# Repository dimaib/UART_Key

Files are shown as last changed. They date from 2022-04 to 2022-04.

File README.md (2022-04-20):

# Smart lock for city scooters
## Description
- This device allows you to block the scooter when charging, preventing premature removal from the rack
- The device also determines whether the scooter is rented or not, thereby blocking or giving it away
- Allows you to determine the speed of the scooter and dynamically change the color of the LED strip depending on the speed.
	>All data is intercepted from UART data line of the scooter.
## Tools and languages
- PCB and circuit diagram created by Altium Designer
- Firmware created in Keil uVision for ARM in C languages

## Main view PCB
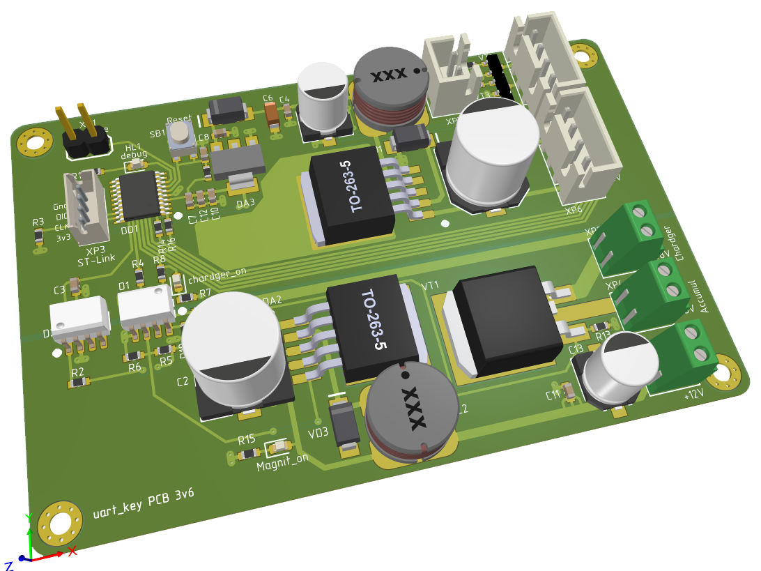
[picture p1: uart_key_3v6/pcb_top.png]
PCB top

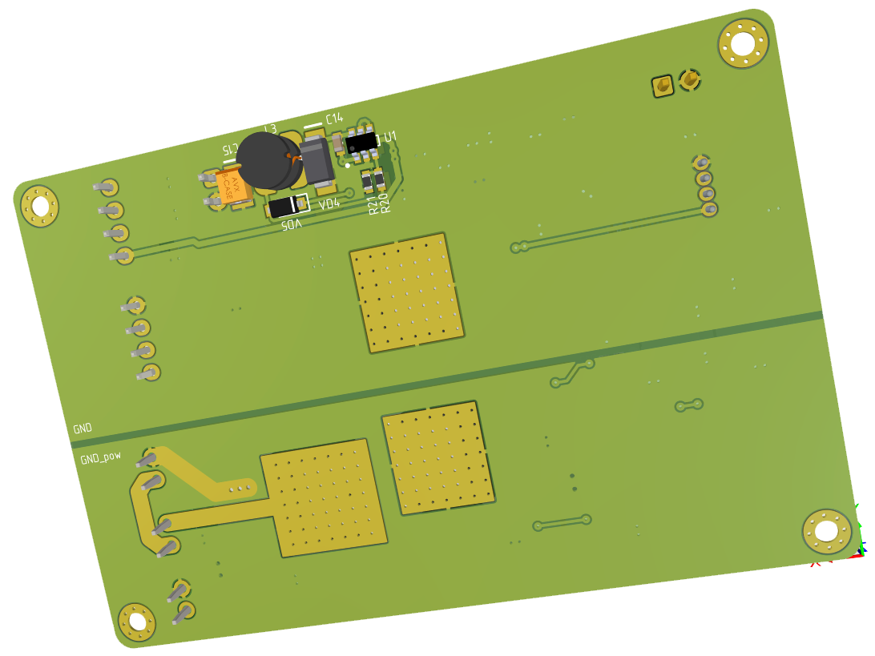
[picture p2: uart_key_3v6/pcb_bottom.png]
PCB bottom


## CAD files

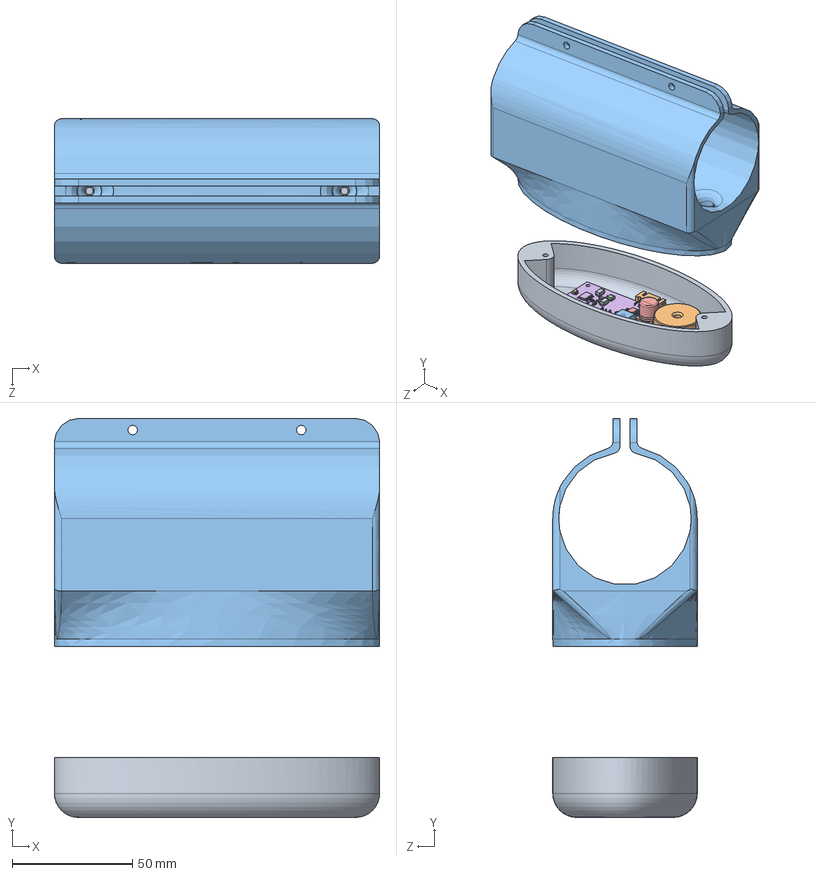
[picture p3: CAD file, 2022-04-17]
box_develop/box.SLDASM
135.0 x 165.6 x 60.0 mm
SOLID.step
SOLID-0.step
SOLID-1.step x 2
SOLID-2.step
SOLID-3.step
SOLID-4.step
SOLID-5.step x 12
SOLID-6.step x 3
SOLID-7.step x 3
SOLID-8.step x 4
SOLID-9.step
SOLID-10.step
COMPOUND.step
Magnet_conn
ZH_02x01_1.5mm
ZH_04x01_1.5mm
magnit
in_os

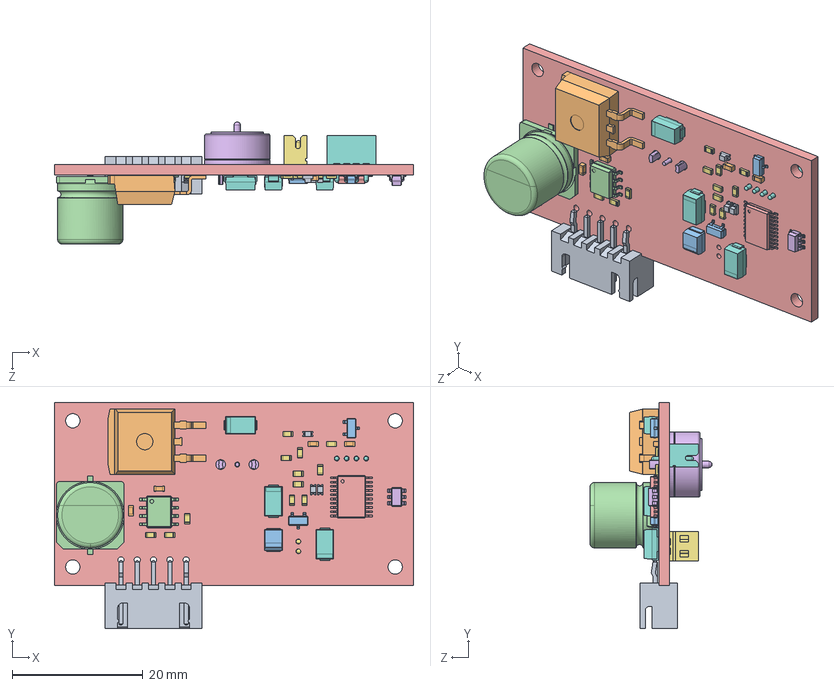
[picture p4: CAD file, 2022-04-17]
box_develop/pcb.SLDASM
55.0 x 34.6 x 18.7 mm
SOLID.step
SOLID-0.step
SOLID-1.step x 2
SOLID-2.step
SOLID-3.step
SOLID-4.step
SOLID-5.step x 12
SOLID-6.step x 3
SOLID-7.step x 3
SOLID-8.step x 4
SOLID-9.step
SOLID-10.step
COMPOUND.step
Magnet_conn
ZH_02x01_1.5mm
ZH_04x01_1.5mm

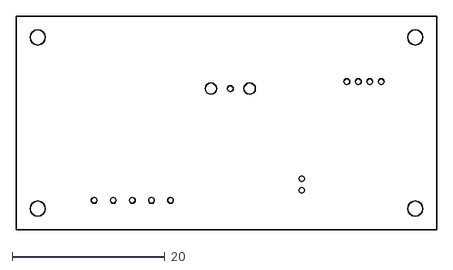
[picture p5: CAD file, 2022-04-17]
uart_key/123/uart_key-drl_map.dxf
55.0 x 28.0

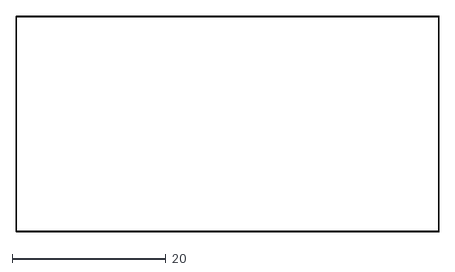
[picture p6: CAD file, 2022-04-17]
uart_key/uart_key-Edge_Cuts.dxf
55.1 x 28.1

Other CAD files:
box_develop/SOT-23.step.SLDASM
box_develop/SOT-23-6.step.SLDASM
box_develop/SOIC-8_3.9x4.9mm_P1.27mm.step.SLDASM
box_develop/TSSOP-20_4.4x6.5mm_P0.65mm.step.SLDASM
box_develop/CP_EIA-3528-21_Kemet-B.step.SLDASM
box_develop/D_SMA.step.SLDASM
box_develop/LED_0603_1608Metric_Castellated.step.SLDASM
box_develop/TO-263-2.step.SLDASM
box_develop/C_0603_1608Metric.step.SLDASM
box_develop/CP_Elec_10x10.5.step.SLDASM
box_develop/JST_XH_B5B-XH-A_1x05_P2.50mm_Vertical.step.SLDASM
box_develop/R_0603_1608Metric.step.SLDASM
box_develop/COMPOUND.step.SLDPRT
box_develop/Magnet_conn.SLDPRT
box_develop/SOLID-0.step.SLDPRT
box_develop/SOLID-1.step.SLDPRT
box_develop/SOLID-10.step.SLDPRT
box_develop/SOLID-2.step.SLDPRT
box_develop/SOLID-3.step.SLDPRT
box_develop/SOLID-4.step.SLDPRT
box_develop/SOLID-5.step.SLDPRT
box_develop/SOLID-6.step.SLDPRT
box_develop/SOLID-7.step.SLDPRT
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

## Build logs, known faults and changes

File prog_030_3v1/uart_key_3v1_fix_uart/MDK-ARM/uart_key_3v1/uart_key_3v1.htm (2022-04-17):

# Static Call Graph for image uart_key_3v1\uart_key_3v1.axf

#<CALLGRAPH># ARM Linker, 5060960: Last Updated: Sat May 29 01:21:32 2021

### Maximum Stack Usage = 216 bytes + Unknown(Cycles, Untraceable Function Pointers)

### Call chain for Maximum Stack Depth:

main ⇒ SystemClock_Config ⇒ HAL_RCC_ClockConfig ⇒ HAL_RCC_GetSysClockFreq ⇒ __aeabi_uldivmod ⇒ __aeabi_llsl

### Mutually Recursive functions

- ADC1_IRQHandler ⇒ ADC1_IRQHandler
- HardFault_Handler ⇒ HardFault_Handler
- NMI_Handler ⇒ NMI_Handler

### Function Pointers

- ADC1_IRQHandler from startup_stm32f030x6.o(.text) referenced from startup_stm32f030x6.o(RESET)
- DMA1_Channel1_IRQHandler from startup_stm32f030x6.o(.text) referenced from startup_stm32f030x6.o(RESET)
- DMA1_Channel2_3_IRQHandler from startup_stm32f030x6.o(.text) referenced from startup_stm32f030x6.o(RESET)
- DMA1_Channel4_5_IRQHandler from startup_stm32f030x6.o(.text) referenced from startup_stm32f030x6.o(RESET)
- EXTI0_1_IRQHandler from startup_stm32f030x6.o(.text) referenced from startup_stm32f030x6.o(RESET)
- EXTI2_3_IRQHandler from startup_stm32f030x6.o(.text) referenced from startup_stm32f030x6.o(RESET)
- EXTI4_15_IRQHandler from startup_stm32f030x6.o(.text) referenced from startup_stm32f030x6.o(RESET)
- FLASH_IRQHandler from startup_stm32f030x6.o(.text) referenced from startup_stm32f030x6.o(RESET)
- HardFault_Handler from stm32f0xx_it.o(i.HardFault_Handler) referenced from startup_stm32f030x6.o(RESET)
- I2C1_IRQHandler from startup_stm32f030x6.o(.text) referenced from startup_stm32f030x6.o(RESET)
- NMI_Handler from stm32f0xx_it.o(i.NMI_Handler) referenced from startup_stm32f030x6.o(RESET)
- PendSV_Handler from stm32f0xx_it.o(i.PendSV_Handler) referenced from startup_stm32f030x6.o(RESET)
- RCC_IRQHandler from startup_stm32f030x6.o(.text) referenced from startup_stm32f030x6.o(RESET)
- RTC_IRQHandler from startup_stm32f030x6.o(.text) referenced from startup_stm32f030x6.o(RESET)
- Reset_Handler from startup_stm32f030x6.o(.text) referenced from startup_stm32f030x6.o(RESET)
- SPI1_IRQHandler from startup_stm32f030x6.o(.text) referenced from startup_stm32f030x6.o(RESET)
- SVC_Handler from stm32f0xx_it.o(i.SVC_Handler) referenced from startup_stm32f030x6.o(RESET)
- SysTick_Handler from stm32f0xx_it.o(i.SysTick_Handler) referenced from startup_stm32f030x6.o(RESET)
- SystemInit from system_stm32f0xx.o(i.SystemInit) referenced from startup_stm32f030x6.o(.text)
- TIM14_IRQHandler from stm32f0xx_it.o(i.TIM14_IRQHandler) referenced from startup_stm32f030x6.o(RESET)
- TIM16_IRQHandler from startup_stm32f030x6.o(.text) referenced from startup_stm32f030x6.o(RESET)
- TIM17_IRQHandler from startup_stm32f030x6.o(.text) referenced from startup_stm32f030x6.o(RESET)
- TIM1_BRK_UP_TRG_COM_IRQHandler from startup_stm32f030x6.o(.text) referenced from startup_stm32f030x6.o(RESET)
- TIM1_CC_IRQHandler from startup_stm32f030x6.o(.text) referenced from startup_stm32f030x6.o(RESET)
- TIM3_IRQHandler from startup_stm32f030x6.o(.text) referenced from startup_stm32f030x6.o(RESET)
- UART_DMAAbortOnError from stm32f0xx_hal_uart.o(i.UART_DMAAbortOnError) referenced from stm32f0xx_hal_uart.o(i.HAL_UART_IRQHandler)
- USART1_IRQHandler from stm32f0xx_it.o(i.USART1_IRQHandler) referenced from startup_stm32f030x6.o(RESET)
- WWDG_IRQHandler from startup_stm32f030x6.o(.text) referenced from startup_stm32f030x6.o(RESET)
- __main from entry.o(.ARM.Collect$$$$00000000) referenced from startup_stm32f030x6.o(.text)
- main from main.o(i.main) referenced from entry9a.o(.ARM.Collect$$$$0000000B)

### Global Symbols

__main (Thumb, 0 bytes, Stack size unknown bytes, entry.o(.ARM.Collect$$$$00000000))
[Address Reference Count : 1]

- startup_stm32f030x6.o(.text)

_main_stk (Thumb, 0 bytes, Stack size unknown bytes, entry2.o(.ARM.Collect$$$$00000001))

_main_scatterload (Thumb, 0 bytes, Stack size unknown bytes, entry5.o(.ARM.Collect$$$$00000004))

[Calls]

- >> __scatterload

__main_after_scatterload (Thumb, 0 bytes, Stack size unknown bytes, entry5.o(.ARM.Collect$$$$00000004))

[Called By]

- >> __scatterload

_main_clock (Thumb, 0 bytes, Stack size unknown bytes, entry7b.o(.ARM.Collect$$$$00000008))

_main_cpp_init (Thumb, 0 bytes, Stack size unknown bytes, entry8b.o(.ARM.Collect$$$$0000000A))

_main_init (Thumb, 0 bytes, Stack size unknown bytes, entry9a.o(.ARM.Collect$$$$0000000B))

__rt_lib_shutdown_fini (Thumb, 0 bytes, Stack size unknown bytes, entry12b.o(.ARM.Collect$$$$0000000E))

[Calls]

- >> __arm_fini_ (Weak Reference)

__rt_final_cpp (Thumb, 0 bytes, Stack size unknown bytes, entry10a.o(.ARM.Collect$$$$0000000F))

__rt_final_exit (Thumb, 0 bytes, Stack size unknown bytes, entry11a.o(.ARM.Collect$$$$00000011))

Reset_Handler (Thumb, 8 bytes, Stack size 0 bytes, startup_stm32f030x6.o(.text))
[Address Reference Count : 1]

- startup_stm32f030x6.o(RESET)

ADC1_IRQHandler (Thumb, 0 bytes, Stack size 0 bytes, startup_stm32f030x6.o(.text))

[Calls]

- >> ADC1_IRQHandler

[Called By]

- >> ADC1_IRQHandler

[Address Reference Count : 1]

- startup_stm32f030x6.o(RESET)

DMA1_Channel1_IRQHandler (Thumb, 0 bytes, Stack size 0 bytes, startup_stm32f030x6.o(.text))
[Address Reference Count : 1]

- startup_stm32f030x6.o(RESET)

DMA1_Channel2_3_IRQHandler (Thumb, 0 bytes, Stack size 0 bytes, startup_stm32f030x6.o(.text))
[Address Reference Count : 1]

- startup_stm32f030x6.o(RESET)

DMA1_Channel4_5_IRQHandler (Thumb, 0 bytes, Stack size 0 bytes, startup_stm32f030x6.o(.text))
[Address Reference Count : 1]

- startup_stm32f030x6.o(RESET)

EXTI0_1_IRQHandler (Thumb, 0 bytes, Stack size 0 bytes, startup_stm32f030x6.o(.text))
[Address Reference Count : 1]

- startup_stm32f030x6.o(RESET)

EXTI2_3_IRQHandler (Thumb, 0 bytes, Stack size 0 bytes, startup_stm32f030x6.o(.text))
[Address Reference Count : 1]

- startup_stm32f030x6.o(RESET)

EXTI4_15_IRQHandler (Thumb, 0 bytes, Stack size 0 bytes, startup_stm32f030x6.o(.text))
[Address Reference Count : 1]

- startup_stm32f030x6.o(RESET)

FLASH_IRQHandler (Thumb, 0 bytes, Stack size 0 bytes, startup_stm32f030x6.o(.text))
[Address Reference Count : 1]

- startup_stm32f030x6.o(RESET)

I2C1_IRQHandler (Thumb, 0 bytes, Stack size 0 bytes, startup_stm32f030x6.o(.text))
[Address Reference Count : 1]

- startup_stm32f030x6.o(RESET)

RCC_IRQHandler (Thumb, 0 bytes, Stack size 0 bytes, startup_stm32f030x6.o(.text))
[Address Reference Count : 1]

- startup_stm32f030x6.o(RESET)

RTC_IRQHandler (Thumb, 0 bytes, Stack size 0 bytes, startup_stm32f030x6.o(.text))
[Address Reference Count : 1]

- startup_stm32f030x6.o(RESET)

SPI1_IRQHandler (Thumb, 0 bytes, Stack size 0 bytes, startup_stm32f030x6.o(.text))
[Address Reference Count : 1]

- startup_stm32f030x6.o(RESET)

TIM16_IRQHandler (Thumb, 0 bytes, Stack size 0 bytes, startup_stm32f030x6.o(.text))
[Address Reference Count : 1]

- startup_stm32f030x6.o(RESET)

TIM17_IRQHandler (Thumb, 0 bytes, Stack size 0 bytes, startup_stm32f030x6.o(.text))
[Address Reference Count : 1]

- startup_stm32f030x6.o(RESET)

TIM1_BRK_UP_TRG_COM_IRQHandler (Thumb, 0 bytes, Stack size 0 bytes, startup_stm32f030x6.o(.text))
[Address Reference Count : 1]

- startup_stm32f030x6.o(RESET)

TIM1_CC_IRQHandler (Thumb, 0 bytes, Stack size 0 bytes, startup_stm32f030x6.o(.text))
[Address Reference Count : 1]

- startup_stm32f030x6.o(RESET)

TIM3_IRQHandler (Thumb, 0 bytes, Stack size 0 bytes, startup_stm32f030x6.o(.text))
[Address Reference Count : 1]

- startup_stm32f030x6.o(RESET)

WWDG_IRQHandler (Thumb, 0 bytes, Stack size 0 bytes, startup_stm32f030x6.o(.text))
[Address Reference Count : 1]

- startup_stm32f030x6.o(RESET)

__aeabi_uidiv (Thumb, 0 bytes, Stack size 12 bytes, uidiv.o(.text), UNUSED)

__aeabi_uidivmod (Thumb, 44 bytes, Stack size 12 bytes, uidiv.o(.text))

[Stack]

- Max Depth = 12
- Call Chain = __aeabi_uidivmod

[Called By]

- >> HAL_InitTick
- >> UART_SetConfig

__aeabi_uldivmod (Thumb, 96 bytes, Stack size 48 bytes, uldiv.o(.text))

[Stack]

- Max Depth = 56
- Call Chain = __aeabi_uldivmod ⇒ __aeabi_llsl

[Calls]

- >> __aeabi_llsl
- >> __aeabi_llsr

[Called By]

- >> HAL_RCC_GetSysClockFreq

__aeabi_llsr (Thumb, 34 bytes, Stack size 8 bytes, llushr.o(.text))

[Stack]

- Max Depth = 8
- Call Chain = __aeabi_llsr

[Called By]

- >> __aeabi_uldivmod

_ll_ushift_r (Thumb, 0 bytes, Stack size 8 bytes, llushr.o(.text), UNUSED)

__aeabi_memset (Thumb, 14 bytes, Stack size 0 bytes, memseta.o(.text), UNUSED)

[Called By]

- >> _memset$wrapper
- >> __aeabi_memclr

__aeabi_memset4 (Thumb, 0 bytes, Stack size 0 bytes, memseta.o(.text), UNUSED)

__aeabi_memset8 (Thumb, 0 bytes, Stack size 0 bytes, memseta.o(.text), UNUSED)

__aeabi_memclr (Thumb, 4 bytes, Stack size 0 bytes, memseta.o(.text), UNUSED)

[Calls]

- >> __aeabi_memset

__aeabi_memclr4 (Thumb, 0 bytes, Stack size 0 bytes, memseta.o(.text))

[Called By]

- >> HAL_UART_MspInit
- >> MX_GPIO_Init
- >> SystemClock_Config

__aeabi_memclr8 (Thumb, 0 bytes, Stack size 0 bytes, memseta.o(.text), UNUSED)

_memset$wrapper (Thumb, 18 bytes, Stack size 8 bytes, memseta.o(.text), UNUSED)

[Calls]

- >> __aeabi_memset

__aeabi_llsl (Thumb, 32 bytes, Stack size 8 bytes, llshl.o(.text))

[Stack]

- Max Depth = 8
- Call Chain = __aeabi_llsl

[Called By]

- >> __aeabi_uldivmod

_ll_shift_l (Thumb, 0 bytes, Stack size 8 bytes, llshl.o(.text), UNUSED)

__scatterload (Thumb, 28 bytes, Stack size 0 bytes, init.o(.text))

[Calls]

- >> __main_after_scatterload

[Called By]

- >> _main_scatterload

__scatterload_rt2 (Thumb, 0 bytes, Stack size 0 bytes, init.o(.text), UNUSED)

Error_Handler (Thumb, 4 bytes, Stack size 0 bytes, main.o(i.Error_Handler))

[Called By]

- >> MX_USART1_UART_Init
- >> MX_TIM14_Init
- >> MX_IWDG_Init

HAL_DMA_Abort_IT (Thumb, 72 bytes, Stack size 16 bytes, stm32f0xx_hal_dma.o(i.HAL_DMA_Abort_IT))

[Stack]

- Max Depth = 16
- Call Chain = HAL_DMA_Abort_IT

[Called By]

- >> HAL_UART_IRQHandler

HAL_Delay (Thumb, 32 bytes, Stack size 16 bytes, stm32f0xx_hal.o(i.HAL_Delay))

[Stack]

- Max Depth = 16
- Call Chain = HAL_Delay

[Calls]

- >> HAL_GetTick

[Called By]

- >> main
- >> command_shell

HAL_GPIO_Init (Thumb, 344 bytes, Stack size 28 bytes, stm32f0xx_hal_gpio.o(i.HAL_GPIO_Init))

[Stack]

- Max Depth = 28
- Call Chain = HAL_GPIO_Init

[Called By]

- >> HAL_UART_MspInit
- >> MX_GPIO_Init

HAL_GPIO_WritePin (Thumb, 12 bytes, Stack size 0 bytes, stm32f0xx_hal_gpio.o(i.HAL_GPIO_WritePin))

[Called By]

- >> MX_GPIO_Init

HAL_GetTick (Thumb, 6 bytes, Stack size 0 bytes, stm32f0xx_hal.o(i.HAL_GetTick))

[Called By]

- >> HAL_IWDG_Init
- >> HAL_RCC_OscConfig
- >> HAL_RCC_ClockConfig
- >> HAL_RCCEx_PeriphCLKConfig
- >> HAL_Delay
- >> UART_WaitOnFlagUntilTimeout
- >> UART_CheckIdleState

HAL_IWDG_Init (Thumb, 86 bytes, Stack size 16 bytes, stm32f0xx_hal_iwdg.o(i.HAL_IWDG_Init))

[Stack]

- Max Depth = 16
- Call Chain = HAL_IWDG_Init

[Calls]

- >> HAL_GetTick

[Called By]

- >> MX_IWDG_Init

HAL_IncTick (Thumb, 12 bytes, Stack size 0 bytes, stm32f0xx_hal.o(i.HAL_IncTick))

[Called By]

- >> SysTick_Handler

HAL_Init (Thumb, 26 bytes, Stack size 8 bytes, stm32f0xx_hal.o(i.HAL_Init))

[Stack]

- Max Depth = 36
- Call Chain = HAL_Init ⇒ HAL_InitTick ⇒ __aeabi_uidivmod

[Calls]

- >> HAL_InitTick
- >> HAL_MspInit

[Called By]

- >> main

HAL_InitTick (Thumb, 58 bytes, Stack size 16 bytes, stm32f0xx_hal.o(i.HAL_InitTick))

[Stack]

- Max Depth = 28
- Call Chain = HAL_InitTick ⇒ __aeabi_uidivmod

[Calls]

- >> HAL_SYSTICK_Config
- >> HAL_NVIC_SetPriority
- >> __aeabi_uidivmod

[Called By]

- >> HAL_RCC_ClockConfig
- >> HAL_Init

HAL_MspInit (Thumb, 34 bytes, Stack size 8 bytes, stm32f0xx_hal_msp.o(i.HAL_MspInit))

[Stack]

- Max Depth = 8
- Call Chain = HAL_MspInit

[Called By]

- >> HAL_Init

HAL_NVIC_EnableIRQ (Thumb, 18 bytes, Stack size 0 bytes, stm32f0xx_hal_cortex.o(i.HAL_NVIC_EnableIRQ))

[Called By]

- >> HAL_UART_MspInit
- >> HAL_TIM_Base_MspInit

HAL_NVIC_SetPriority (Thumb, 8 bytes, Stack size 8 bytes, stm32f0xx_hal_cortex.o(i.HAL_NVIC_SetPriority))

[Stack]

- Max Depth = 8
- Call Chain = HAL_NVIC_SetPriority

[Calls]

- >> __NVIC_SetPriority

[Called By]

- >> HAL_InitTick
- >> HAL_UART_MspInit
- >> HAL_TIM_Base_MspInit

HAL_RCCEx_PeriphCLKConfig (Thumb, 218 bytes, Stack size 24 bytes, stm32f0xx_hal_rcc_ex.o(i.HAL_RCCEx_PeriphCLKConfig))

[Stack]

- Max Depth = 24
- Call Chain = HAL_RCCEx_PeriphCLKConfig

[Calls]

- >> HAL_GetTick

[Called By]

- >> SystemClock_Config

HAL_RCC_ClockConfig (Thumb, 242 bytes, Stack size 24 bytes, stm32f0xx_hal_rcc.o(i.HAL_RCC_ClockConfig))

[Stack]

- Max Depth = 120
- Call Chain = HAL_RCC_ClockConfig ⇒ HAL_RCC_GetSysClockFreq ⇒ __aeabi_uldivmod ⇒ __aeabi_llsl

[Calls]

- >> HAL_InitTick
- >> HAL_RCC_GetSysClockFreq
- >> HAL_GetTick

[Called By]

- >> SystemClock_Config

HAL_RCC_GetPCLK1Freq (Thumb, 20 bytes, Stack size 0 bytes, stm32f0xx_hal_rcc.o(i.HAL_RCC_GetPCLK1Freq))

[Called By]

- >> UART_SetConfig

HAL_RCC_GetSysClockFreq (Thumb, 84 bytes, Stack size 40 bytes, stm32f0xx_hal_rcc.o(i.HAL_RCC_GetSysClockFreq))

[Stack]

- Max Depth = 96
- Call Chain = HAL_RCC_GetSysClockFreq ⇒ __aeabi_uldivmod ⇒ __aeabi_llsl

[Calls]

- >> __ARM_common_ll_muluu
- >> __aeabi_uldivmod

[Called By]

- >> HAL_RCC_ClockConfig
- >> UART_SetConfig

HAL_RCC_OscConfig (Thumb, 890 bytes, Stack size 32 bytes, stm32f0xx_hal_rcc.o(i.HAL_RCC_OscConfig))

[Stack]

- Max Depth = 32
- Call Chain = HAL_RCC_OscConfig

[Calls]

- >> HAL_GetTick

[Called By]

- >> SystemClock_Config

HAL_SYSTICK_Config (Thumb, 38 bytes, Stack size 8 bytes, stm32f0xx_hal_cortex.o(i.HAL_SYSTICK_Config))

[Stack]

- Max Depth = 8
- Call Chain = HAL_SYSTICK_Config

[Calls]

- >> __NVIC_SetPriority

[Called By]

- >> HAL_InitTick

HAL_TIMEx_BreakCallback (Thumb, 2 bytes, Stack size 0 bytes, stm32f0xx_hal_tim_ex.o(i.HAL_TIMEx_BreakCallback))

[Called By]

- >> HAL_TIM_IRQHandler

HAL_TIMEx_CommutCallback (Thumb, 2 bytes, Stack size 0 bytes, stm32f0xx_hal_tim_ex.o(i.HAL_TIMEx_CommutCallback))

[Called By]

- >> HAL_TIM_IRQHandler

HAL_TIM_Base_Init (Thumb, 52 bytes, Stack size 16 bytes, stm32f0xx_hal_tim.o(i.HAL_TIM_Base_Init))

[Stack]

- Max Depth = 32
- Call Chain = HAL_TIM_Base_Init ⇒ HAL_TIM_Base_MspInit ⇒ HAL_NVIC_SetPriority

[Calls]

- >> HAL_TIM_Base_MspInit
- >> TIM_Base_SetConfig

[Called By]

- >> MX_TIM14_Init

HAL_TIM_Base_MspInit (Thumb, 44 bytes, Stack size 8 bytes, tim.o(i.HAL_TIM_Base_MspInit))

[Stack]

- Max Depth = 16
- Call Chain = HAL_TIM_Base_MspInit ⇒ HAL_NVIC_SetPriority

[Calls]

- >> HAL_NVIC_SetPriority
- >> HAL_NVIC_EnableIRQ

[Called By]

- >> HAL_TIM_Base_Init

HAL_TIM_Base_Start_IT (Thumb, 32 bytes, Stack size 0 bytes, stm32f0xx_hal_tim.o(i.HAL_TIM_Base_Start_IT))

[Called By]

- >> main

HAL_TIM_IC_CaptureCallback (Thumb, 2 bytes, Stack size 0 bytes, stm32f0xx_hal_tim.o(i.HAL_TIM_IC_CaptureCallback))

[Called By]

- >> HAL_TIM_IRQHandler

HAL_TIM_IRQHandler (Thumb, 354 bytes, Stack size 16 bytes, stm32f0xx_hal_tim.o(i.HAL_TIM_IRQHandler))

[Stack]

- Max Depth = 16
- Call Chain = HAL_TIM_IRQHandler

[Calls]

- >> HAL_TIM_TriggerCallback
- >> HAL_TIM_PeriodElapsedCallback
- >> HAL_TIM_PWM_PulseFinishedCallback
- >> HAL_TIM_OC_DelayElapsedCallback
- >> HAL_TIM_IC_CaptureCallback
- >> HAL_TIMEx_CommutCallback
- >> HAL_TIMEx_BreakCallback

[Called By]

- >> TIM14_IRQHandler

HAL_TIM_OC_DelayElapsedCallback (Thumb, 2 bytes, Stack size 0 bytes, stm32f0xx_hal_tim.o(i.HAL_TIM_OC_DelayElapsedCallback))

[Called By]

- >> HAL_TIM_IRQHandler

HAL_TIM_PWM_PulseFinishedCallback (Thumb, 2 bytes, Stack size 0 bytes, stm32f0xx_hal_tim.o(i.HAL_TIM_PWM_PulseFinishedCallback))

[Called By]

- >> HAL_TIM_IRQHandler

HAL_TIM_PeriodElapsedCallback (Thumb, 2 bytes, Stack size 0 bytes, stm32f0xx_hal_tim.o(i.HAL_TIM_PeriodElapsedCallback))

[Called By]

- >> HAL_TIM_IRQHandler

HAL_TIM_TriggerCallback (Thumb, 2 bytes, Stack size 0 bytes, stm32f0xx_hal_tim.o(i.HAL_TIM_TriggerCallback))

[Called By]

- >> HAL_TIM_IRQHandler

HAL_UART_ErrorCallback (Thumb, 2 bytes, Stack size 0 bytes, stm32f0xx_hal_uart.o(i.HAL_UART_ErrorCallback))

[Called By]

- >> HAL_UART_IRQHandler
- >> UART_DMAAbortOnError

HAL_UART_IRQHandler (Thumb, 320 bytes, Stack size 24 bytes, stm32f0xx_hal_uart.o(i.HAL_UART_IRQHandler))

[Stack]

- Max Depth = 40
- Call Chain = HAL_UART_IRQHandler ⇒ HAL_DMA_Abort_IT

[Calls]

- >> HAL_DMA_Abort_IT
- >> HAL_UART_TxCpltCallback
- >> HAL_UART_ErrorCallback
- >> UART_EndRxTransfer

[Called By]

- >> USART1_IRQHandler

HAL_UART_Init (Thumb, 106 bytes, Stack size 8 bytes, stm32f0xx_hal_uart.o(i.HAL_UART_Init))

[Stack]

- Max Depth = 120
- Call Chain = HAL_UART_Init ⇒ UART_SetConfig ⇒ HAL_RCC_GetSysClockFreq ⇒ __aeabi_uldivmod ⇒ __aeabi_llsl

[Calls]

- >> HAL_UART_MspInit
- >> UART_SetConfig
- >> UART_CheckIdleState
- >> UART_AdvFeatureConfig

[Called By]

- >> MX_USART1_UART_Init

HAL_UART_MspInit (Thumb, 106 bytes, Stack size 32 bytes, usart.o(i.HAL_UART_MspInit))

[Stack]

- Max Depth = 60
- Call Chain = HAL_UART_MspInit ⇒ HAL_GPIO_Init

[Calls]

- >> HAL_NVIC_SetPriority
- >> HAL_NVIC_EnableIRQ
- >> HAL_GPIO_Init
- >> __aeabi_memclr4

[Called By]

- >> HAL_UART_Init

HAL_UART_TxCpltCallback (Thumb, 2 bytes, Stack size 0 bytes, stm32f0xx_hal_uart.o(i.HAL_UART_TxCpltCallback))

[Called By]

- >> HAL_UART_IRQHandler

HardFault_Handler (Thumb, 2 bytes, Stack size 0 bytes, stm32f0xx_it.o(i.HardFault_Handler))

[Calls]

- >> HardFault_Handler

[Called By]

- >> HardFault_Handler

[Address Reference Count : 1]

- startup_stm32f030x6.o(RESET)

MX_GPIO_Init (Thumb, 156 bytes, Stack size 48 bytes, gpio.o(i.MX_GPIO_Init))

[Stack]

- Max Depth = 76
- Call Chain = MX_GPIO_Init ⇒ HAL_GPIO_Init

[Calls]

- >> HAL_GPIO_WritePin
- >> HAL_GPIO_Init
- >> __aeabi_memclr4

[Called By]

- >> main

MX_IWDG_Init (Thumb, 34 bytes, Stack size 8 bytes, iwdg.o(i.MX_IWDG_Init))

[Stack]

- Max Depth = 24
- Call Chain = MX_IWDG_Init ⇒ HAL_IWDG_Init

[Calls]

- >> HAL_IWDG_Init
- >> Error_Handler

[Called By]

- >> main

MX_TIM14_Init (Thumb, 38 bytes, Stack size 8 bytes, tim.o(i.MX_TIM14_Init))

[Stack]

- Max Depth = 40
- Call Chain = MX_TIM14_Init ⇒ HAL_TIM_Base_Init ⇒ HAL_TIM_Base_MspInit ⇒ HAL_NVIC_SetPriority

[Calls]

- >> HAL_TIM_Base_Init
- >> Error_Handler

[Called By]

- >> main

MX_USART1_UART_Init (Thumb, 48 bytes, Stack size 8 bytes, usart.o(i.MX_USART1_UART_Init))

[Stack]

- Max Depth = 128
- Call Chain = MX_USART1_UART_Init ⇒ HAL_UART_Init ⇒ UART_SetConfig ⇒ HAL_RCC_GetSysClockFreq ⇒ __aeabi_uldivmod ⇒ __aeabi_llsl

[Calls]

- >> HAL_UART_Init
- >> Error_Handler

[Called By]

- >> main

NMI_Handler (Thumb, 2 bytes, Stack size 0 bytes, stm32f0xx_it.o(i.NMI_Handler))

[Calls]

- >> NMI_Handler

[Called By]

- >> NMI_Handler

[Address Reference Count : 1]

- startup_stm32f030x6.o(RESET)

PendSV_Handler (Thumb, 2 bytes, Stack size 0 bytes, stm32f0xx_it.o(i.PendSV_Handler))
[Address Reference Count : 1]

- startup_stm32f030x6.o(RESET)

SVC_Handler (Thumb, 2 bytes, Stack size 0 bytes, stm32f0xx_it.o(i.SVC_Handler))
[Address Reference Count : 1]

- startup_stm32f030x6.o(RESET)

SysTick_Handler (Thumb, 8 bytes, Stack size 8 bytes, stm32f0xx_it.o(i.SysTick_Handler))

[Stack]

- Max Depth = 8
- Call Chain = SysTick_Handler

[Calls]

- >> HAL_IncTick

[Address Reference Count : 1]

- startup_stm32f030x6.o(RESET)

SystemClock_Config (Thumb, 120 bytes, Stack size 96 bytes, main.o(i.SystemClock_Config))

[Stack]

- Max Depth = 216
- Call Chain = SystemClock_Config ⇒ HAL_RCC_ClockConfig ⇒ HAL_RCC_GetSysClockFreq ⇒ __aeabi_uldivmod ⇒ __aeabi_llsl

[Calls]

- >> HAL_RCC_OscConfig
- >> HAL_RCC_ClockConfig
- >> HAL_RCCEx_PeriphCLKConfig
- >> __aeabi_memclr4

[Called By]

- >> main

SystemInit (Thumb, 2 bytes, Stack size 0 bytes, system_stm32f0xx.o(i.SystemInit))
[Address Reference Count : 1]

- startup_stm32f030x6.o(.text)

TIM14_IRQHandler (Thumb, 86 bytes, Stack size 8 bytes, stm32f0xx_it.o(i.TIM14_IRQHandler))

[Stack]

- Max Depth = 24
- Call Chain = TIM14_IRQHandler ⇒ HAL_TIM_IRQHandler

[Calls]

- >> HAL_TIM_IRQHandler

[Address Reference Count : 1]

- startup_stm32f030x6.o(RESET)

TIM_Base_SetConfig (Thumb, 100 bytes, Stack size 16 bytes, stm32f0xx_hal_tim.o(i.TIM_Base_SetConfig))

[Stack]

- Max Depth = 16
- Call Chain = TIM_Base_SetConfig

[Called By]

- >> HAL_TIM_Base_Init

UART_AdvFeatureConfig (Thumb, 202 bytes, Stack size 8 bytes, stm32f0xx_hal_uart.o(i.UART_AdvFeatureConfig))

[Stack]

- Max Depth = 8
- Call Chain = UART_AdvFeatureConfig

[Called By]

- >> HAL_UART_Init

UART_CheckIdleState (Thumb, 90 bytes, Stack size 24 bytes, stm32f0xx_hal_uart.o(i.UART_CheckIdleState))

[Stack]

- Max Depth = 64
- Call Chain = UART_CheckIdleState ⇒ UART_WaitOnFlagUntilTimeout

[Calls]

- >> HAL_GetTick
- >> UART_WaitOnFlagUntilTimeout

[Called By]

- >> HAL_UART_Init

UART_SetConfig (Thumb, 282 bytes, Stack size 16 bytes, stm32f0xx_hal_uart.o(i.UART_SetConfig))

[Stack]

- Max Depth = 112
- Call Chain = UART_SetConfig ⇒ HAL_RCC_GetSysClockFreq ⇒ __aeabi_uldivmod ⇒ __aeabi_llsl

[Calls]

- >> HAL_RCC_GetSysClockFreq
- >> HAL_RCC_GetPCLK1Freq
- >> __aeabi_uidivmod

[Called By]

- >> HAL_UART_Init

UART_WaitOnFlagUntilTimeout (Thumb, 156 bytes, Stack size 40 bytes, stm32f0xx_hal_uart.o(i.UART_WaitOnFlagUntilTimeout))

[Stack]

- Max Depth = 40
- Call Chain = UART_WaitOnFlagUntilTimeout

[Calls]

- >> HAL_GetTick

[Called By]

- >> UART_CheckIdleState

USART1_IRQHandler (Thumb, 208 bytes, Stack size 24 bytes, stm32f0xx_it.o(i.USART1_IRQHandler))

[Stack]

- Max Depth = 64
- Call Chain = USART1_IRQHandler ⇒ HAL_UART_IRQHandler ⇒ HAL_DMA_Abort_IT

[Calls]

- >> HAL_UART_IRQHandler
- >> crc16_traker

[Address Reference Count : 1]

- startup_stm32f030x6.o(RESET)

__ARM_common_ll_muluu (Thumb, 48 bytes, Stack size 24 bytes, stm32f0xx_hal_rcc.o(i.__ARM_common_ll_muluu))

[Stack]

- Max Depth = 24
- Call Chain = __ARM_common_ll_muluu

[Called By]

- >> HAL_RCC_GetSysClockFreq

__scatterload_copy (Thumb, 14 bytes, Stack size unknown bytes, handlers.o(i.__scatterload_copy), UNUSED)

__scatterload_null (Thumb, 2 bytes, Stack size unknown bytes, handlers.o(i.__scatterload_null), UNUSED)

__scatterload_zeroinit (Thumb, 14 bytes, Stack size unknown bytes, handlers.o(i.__scatterload_zeroinit), UNUSED)

command_shell (Thumb, 68 bytes, Stack size 8 bytes, function.o(i.command_shell))

[Stack]

- Max Depth = 24
- Call Chain = command_shell ⇒ HAL_Delay

[Calls]

- >> HAL_Delay

[Called By]

- >> main

crc16_traker (Thumb, 56 bytes, Stack size 12 bytes, function.o(i.crc16_traker))

[Stack]

- Max Depth = 12
- Call Chain = crc16_traker

[Called By]

- >> USART1_IRQHandler

led_control (Thumb, 164 bytes, Stack size 20 bytes, function.o(i.led_control))

[Stack]

- Max Depth = 20
- Call Chain = led_control

[Called By]

- >> main

main (Thumb, 284 bytes, Stack size 0 bytes, main.o(i.main))

[Stack]

- Max Depth = 216
- Call Chain = main ⇒ SystemClock_Config ⇒ HAL_RCC_ClockConfig ⇒ HAL_RCC_GetSysClockFreq ⇒ __aeabi_uldivmod ⇒ __aeabi_llsl

[Calls]

- >> MX_USART1_UART_Init
- >> MX_TIM14_Init
- >> MX_IWDG_Init
- >> MX_GPIO_Init
- >> HAL_TIM_Base_Start_IT
- >> HAL_Init
- >> SystemClock_Config
- >> HAL_Delay
- >> led_control
- >> command_shell

[Address Reference Count : 1]

- entry9a.o(.ARM.Collect$$$$0000000B)

### Local Symbols

__NVIC_SetPriority (Thumb, 60 bytes, Stack size 0 bytes, stm32f0xx_hal_cortex.o(i.__NVIC_SetPriority))

[Called By]

- >> HAL_SYSTICK_Config
- >> HAL_NVIC_SetPriority

UART_DMAAbortOnError (Thumb, 20 bytes, Stack size 8 bytes, stm32f0xx_hal_uart.o(i.UART_DMAAbortOnError))

[Stack]

- Max Depth = 8
- Call Chain = UART_DMAAbortOnError

[Calls]

- >> HAL_UART_ErrorCallback

[Address Reference Count : 1]

- stm32f0xx_hal_uart.o(i.HAL_UART_IRQHandler)

UART_EndRxTransfer (Thumb, 32 bytes, Stack size 0 bytes, stm32f0xx_hal_uart.o(i.UART_EndRxTransfer))

[Called By]

- >> HAL_UART_IRQHandler

### Undefined Global Symbols

__arm_fini_ (Unknown, 0 bytes, Stack size 0 bytes, UNDEFINED)

[Called By]

- >> __rt_lib_shutdown_fini

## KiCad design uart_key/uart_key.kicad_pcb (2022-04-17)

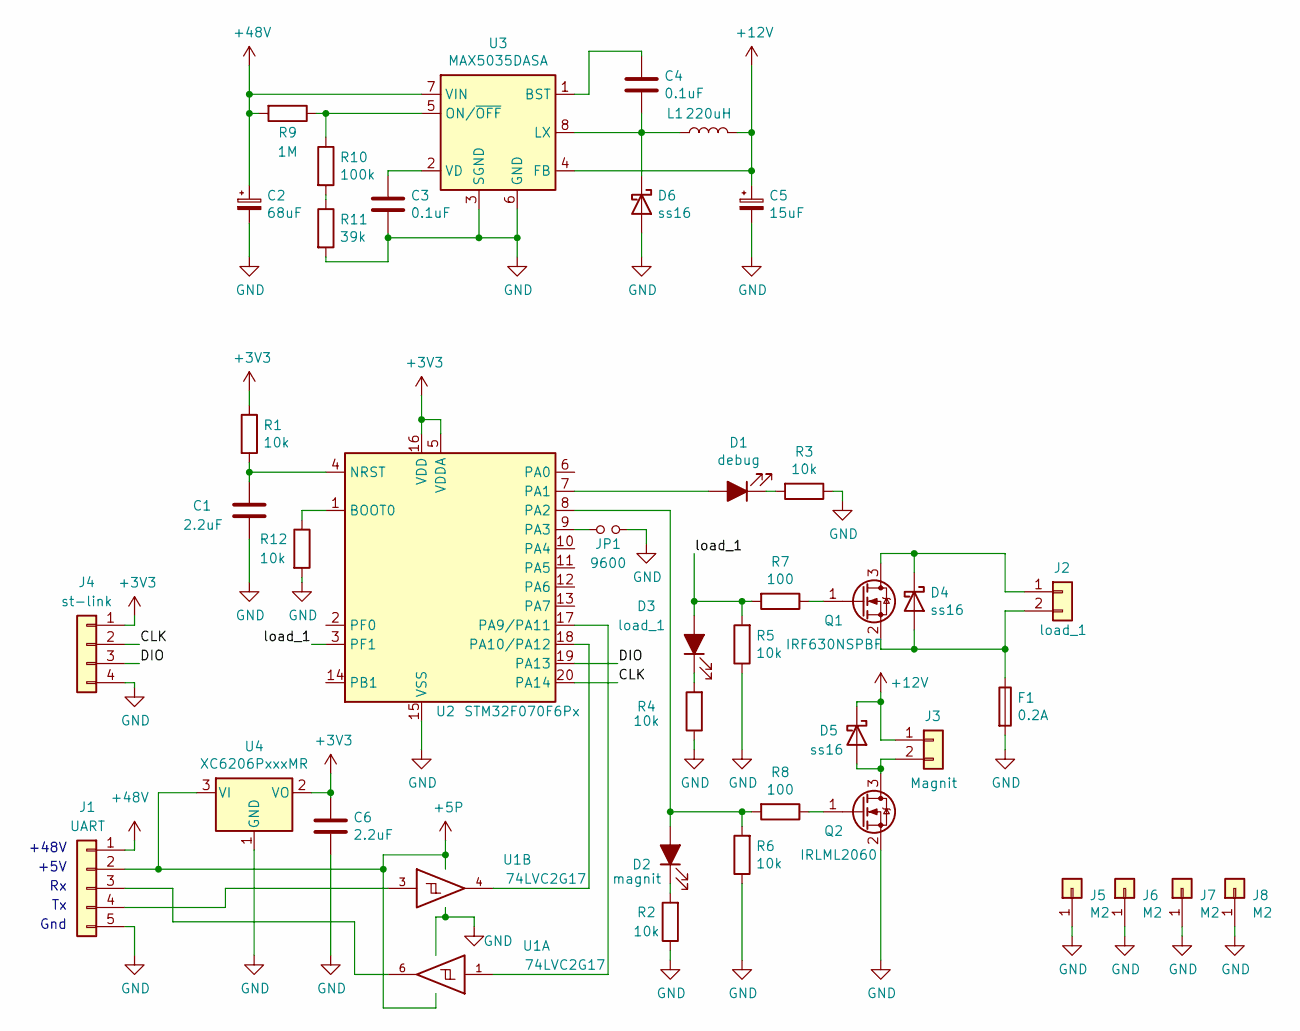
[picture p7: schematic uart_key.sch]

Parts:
C1, C6: 2.2uF; C_0603_1608Metric
C2: 68uF; CP_Elec_10x10.5
C3, C4: 0.1uF; C_0603_1608Metric
C5: 15uF; CP_EIA-3528-21_Kemet-B
D1: debug; LED_0603_1608Metric_Castellated
D2: magnit; LED_0603_1608Metric_Castellated
D3: load_1; LED_0603_1608Metric_Castellated
D4, D5, D6: ss16; D_SMA
F1: 0.2А; Fuse_1812_4532Metric
J1: UART; JST_XH_B5B-XH-A_1x05_P2.50mm_Vertical
J2: load_1; magnet_conn
J3: Magnit; ZH_Conn_02x01
J4: st-link; ZH_Conn_04x01
J5, J6, J7, J8: M2; MountingHole_2.2mm_M2_ISO7380_Pad_TopBottom
JP1: 9600; SolderJumper-2_P1.3mm_Open_TrianglePad1.0x1.5mm
L1: 220uH; L_10.4x10.4_H4.8
Q1: IRF630NSPBF; TO-263-2
Q2: IRLML2060; SOT-23
R1, R2, R3, R4, R5, R6, R12: 10k; R_0603_1608Metric
R7, R8: 100; R_0603_1608Metric
R9: 1M; R_0603_1608Metric
R10: 100k; R_0603_1608Metric
R11: 39k; R_0603_1608Metric
U1: 74LVC2G17; SOT-23-6
U2: STM32F070F6Px; TSSOP-20_4.4x6.5mm_P0.65mm
U3: MAX5035DASA; SOIC-8_3.9x4.9mm_P1.27mm
U4: XC6206PxxxMR; SOT-23

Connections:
+3V3: C6.1, J4.1, R1.1, U2.5 (VDDA), U2.16 (VDD), U4.2 (VO)
+5P: J1.2, U1.5 (VCC), U4.3 (VI)
+12V: C5.1, D5.1 (K), J3.1, L1.2, U3.4 (FB)
+48V: C2.1, J1.1, R9.2, U3.7 (VIN)
/CLK: J4.2, U2.20 (PA14)
/DIO: J4.3, U2.19 (PA13)
/load_1: D3.2 (A), R5.2, R7.2, U2.3 (PF1)
GND: C1.2, C2.2, C3.2, C5.2, C6.2, D6.2 (A), F1.2, J1.5, J4.4, J5.1, J6.1, J7.1, J8.1, JP1.2, Q2.2 (S), R2.1, R3.1, R4.1, R5.1, R6.1, R11.2, R12.2, U1.2 (GND), U2.15 (VSS), U3.3 (SGND), U3.6 (GND), U4.1 (GND)
unnamed: C1.1, R1.2, U2.4 (NRST)
unnamed: C3.1, U3.2 (VD)
unnamed: C4.1, U3.1 (BST)
unnamed: C4.2, D6.1 (K), L1.1, U3.8 (LX)
unnamed: D1.1 (K), R3.2
unnamed: D1.2 (A), U2.7 (PA1)
unnamed: D2.1 (K), R2.2
unnamed: D2.2 (A), R6.2, R8.2, U2.8 (PA2)
unnamed: D3.1 (K), R4.2
unnamed: D4.1 (K), J2.1, Q1.3 (D)
unnamed: D4.2 (A), F1.1, J2.2, Q1.2 (S)
unnamed: D5.2 (A), J3.2, Q2.3 (D)
unnamed: J1.3, U1.6
unnamed: J1.4, U1.3
unnamed: JP1.1, U2.9 (PA3)
unnamed: Q1.1 (G), R7.1
unnamed: Q2.1 (G), R8.1
unnamed: R9.1, R10.1, U3.5 (ON/~OFF~)
unnamed: R10.2, R11.1
unnamed: R12.1, U2.1 (BOOT0)
unnamed: U1.1, U2.17 (PA9/PA11)
unnamed: U1.4, U2.18 (PA10/PA12)

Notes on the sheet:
+5V
Gnd
+48V

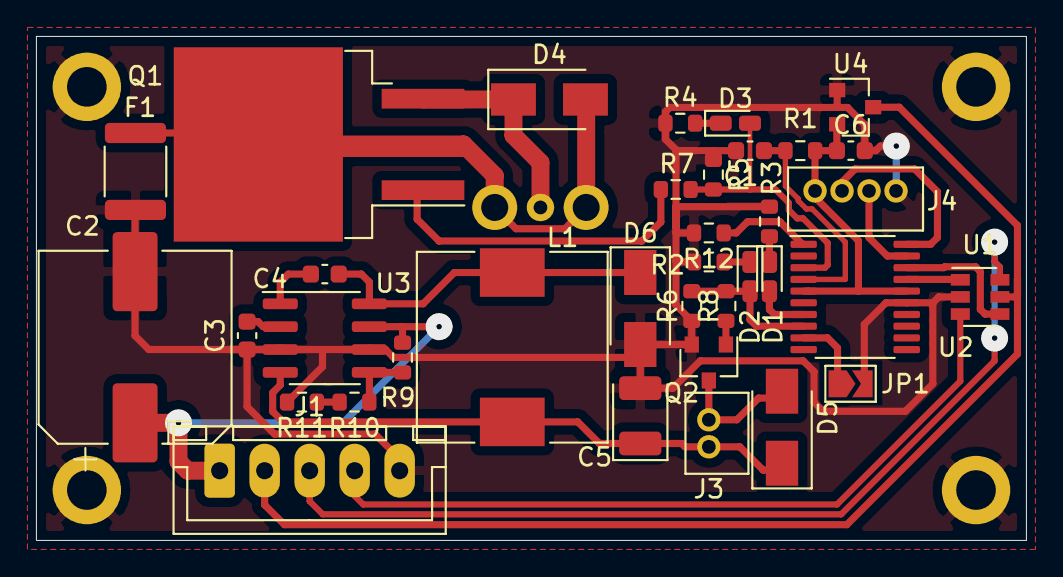
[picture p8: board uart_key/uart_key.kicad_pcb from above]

Board: 2 copper layers, 55.0 x 28.0 mm, 41 parts (0 on the bottom side), 30 nets.

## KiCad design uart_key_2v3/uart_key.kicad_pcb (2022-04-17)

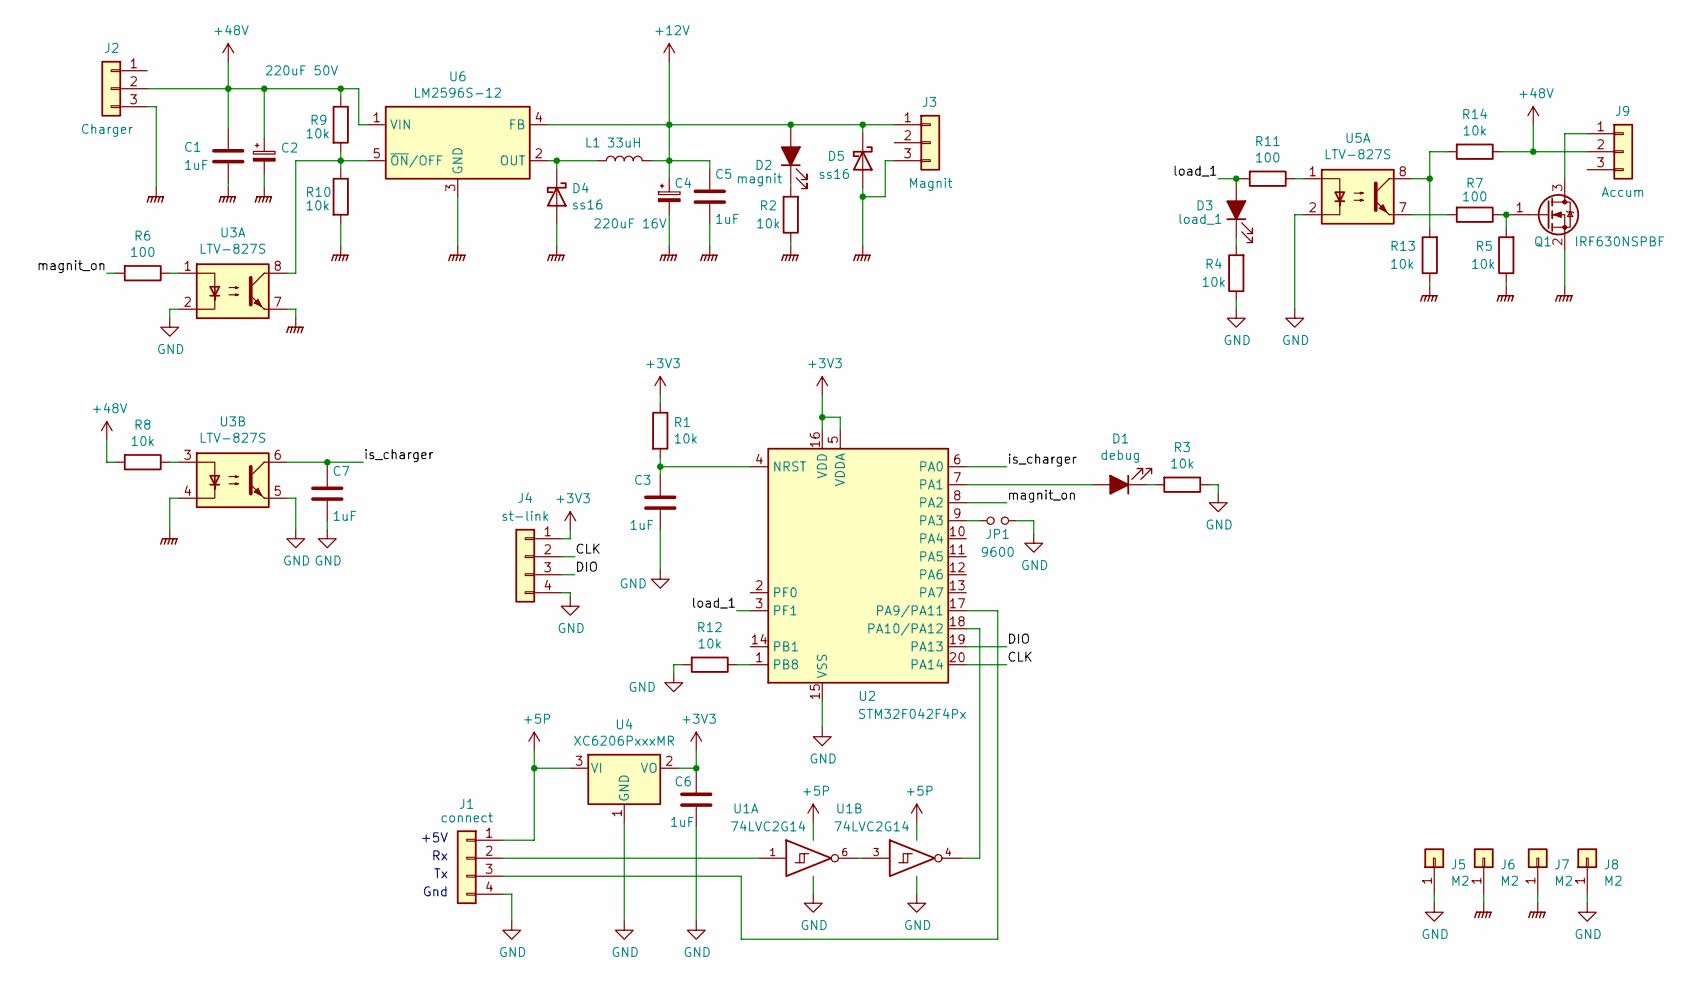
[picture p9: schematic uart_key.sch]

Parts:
C1, C3, C5, C6, C7: 1uF; C_0603_1608Metric
C2: 220uF 50V; CP_Elec_10x10.5
C4: 220uF 16V; CP_Elec_6.3x7.7
D1: debug; LED_0603_1608Metric_Castellated
D2: magnit; LED_0603_1608Metric_Castellated
D3: load_1; LED_0603_1608Metric_Castellated
D4, D5: ss16; D_SMA
J1: connect; JST_XH_B4B-XH-A_1x04_P2.50mm_Vertical
J2: Charger; JST_XH_B3B-XH-A_1x03_P2.50mm_Vertical
J3: Magnit; JST_XH_B3B-XH-A_1x03_P2.50mm_Vertical
J4: st-link; ZH_Conn_04x01
J5, J6, J7, J8: M2; MountingHole_2.2mm_M2_Pad_Via
J9: Accum; JST_XH_B3B-XH-A_1x03_P2.50mm_Vertical
JP1: 9600; PinHeader_1x02_P2.54mm_Vertical
L1: 33uH; SDR_1006
Q1: IRF630NSPBF; TO-263-2
R1, R2, R3, R4, R5, R8, R9, R10, R12, R13, R14: 10k; R_0603_1608Metric
R6, R7, R11: 100; R_0603_1608Metric
U1: 74LVC2G14; SOT-23-6
U2: STM32F042F4Px; TSSOP-20_4.4x6.5mm_P0.65mm
U3, U5: LTV-827S; SMDIP-8_W9.53mm
U4: XC6206PxxxMR; SOT-23
U6: LM2596S-12; TO-263-5_TabPin3

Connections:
+3V3: C6.1, J4.1, R1.1, U2.5 (VDDA), U2.16 (VDD), U4.2 (VO)
+5P: J1.1, U1.5 (VCC), U4.3 (VI)
+12V: C4.1, C5.1, D2.2 (A), D5.1 (K), J3.1, L1.2, U6.4 (FB)
+48V: C1.1, C2.1, J2.2, J9.2, R8.2, R9.1, R14.1, U6.1 (VIN)
/CLK: J4.2, U2.20 (PA14)
/DIO: J4.3, U2.19 (PA13)
/is_charger: C7.1, U2.6 (PA0), U3.6
/load_1: D3.2 (A), R11.2, U2.3 (PF1)
/magnit_on: R6.2, U2.8 (PA2)
GND: C3.2, C6.2, C7.2, J1.4, J4.4, J5.1, J8.1, JP1.2, R3.1, R4.1, R12.2, U1.2 (GND), U2.15 (VSS), U3.2, U3.5, U4.1 (GND), U5.2
GNDPWR: C1.2, C2.2, C4.2, C5.2, D4.2 (A), D5.2 (A), J2.3, J3.3, J6.1, J7.1, Q1.2 (S), R2.1, R5.1, R10.2, R13.1, U3.4, U3.7, U6.3 (GND)
unnamed: C3.1, R1.2, U2.4 (NRST)
unnamed: D1.1 (K), R3.2
unnamed: D1.2 (A), U2.7 (PA1)
unnamed: D2.1 (K), R2.2
unnamed: D3.1 (K), R4.2
unnamed: D4.1 (K), L1.1, U6.2 (OUT)
unnamed: J1.2, U1.1
unnamed: J1.3, U2.17 (PA9/PA11)
unnamed: J9.1, Q1.3 (D)
unnamed: JP1.1, U2.9 (PA3)
unnamed: Q1.1 (G), R5.2, R7.1
unnamed: R6.1, U3.1
unnamed: R7.2, U5.7
unnamed: R8.1, U3.3
unnamed: R9.2, R10.1, U3.8, U6.5 (~ON~/OFF)
unnamed: R11.1, U5.1
unnamed: R12.1, U2.1 (PB8)
unnamed: R13.2, R14.2, U5.8
unnamed: U1.3, U1.6
unnamed: U1.4, U2.18 (PA10/PA12)

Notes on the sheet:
+5V
Gnd

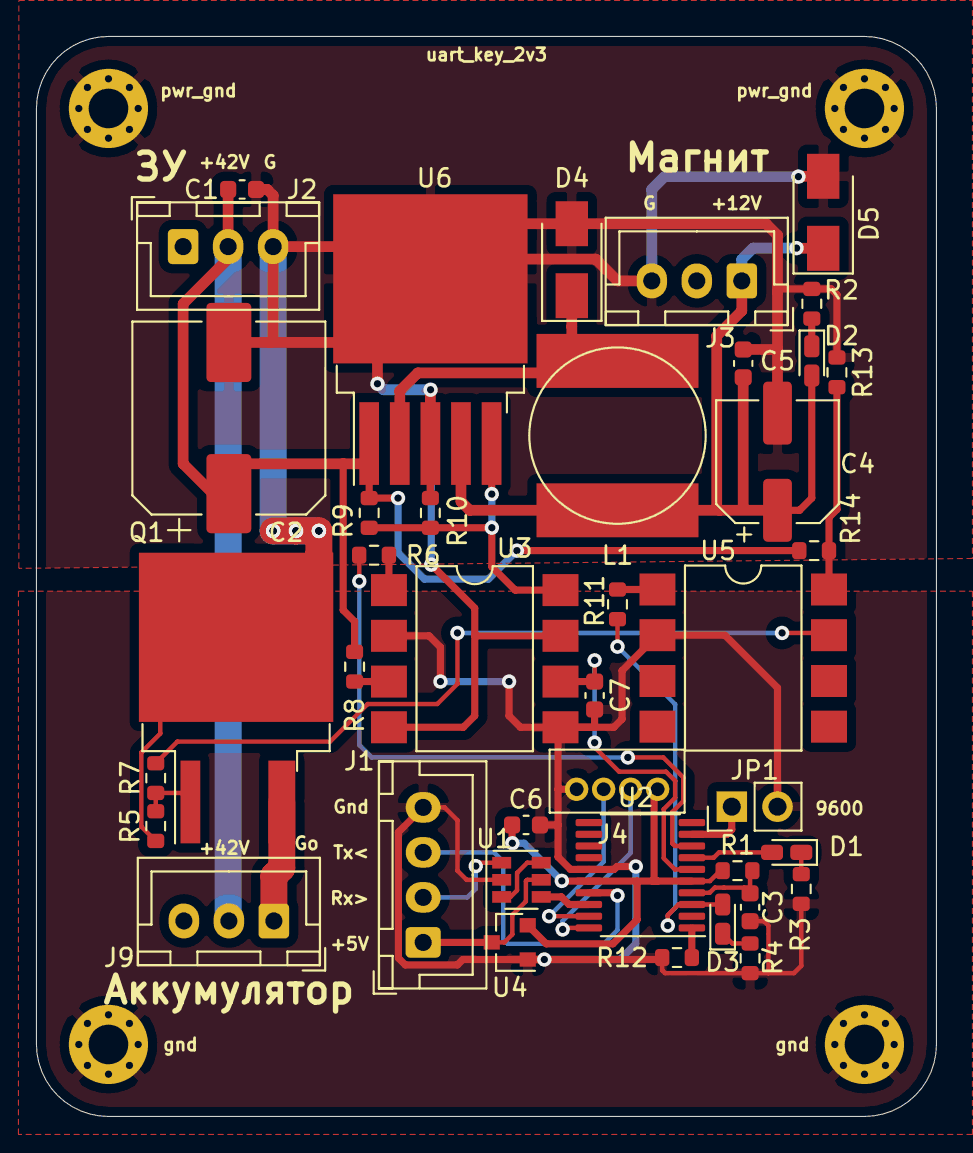
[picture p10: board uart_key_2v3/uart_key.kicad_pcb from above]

Board: 2 copper layers, 50.0 x 60.0 mm, 44 parts (0 on the bottom side), 31 nets.

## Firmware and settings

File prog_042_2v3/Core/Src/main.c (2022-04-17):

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
/* Includes ------------------------------------------------------------------*/
#include "main.h"
#include "usart.h"
#include "gpio.h"

/* USER CODE BEGIN PTD */
/* USER CODE BEGIN 0 */

/* USER CODE END PTD */


void SystemClock_Config(void);
/* USER CODE BEGIN PFP */
uint8_t status=0;																																										//переменная для хранения статуса
uint8_t command=0;																																									//команды для передачи в main
uint32_t uart_baud=115200;																																					//скорость UART

uint16_t del_val=600;

extern uint8_t msg_on_1[];																																					//массив команды 1
extern uint8_t msg_on_2[];																																					//массив команды 2


void command_shell()																																									//функция для обработки команд в переменной command
{
	if(command){
		if(command&(1<<0)){																																								//команда открыть закрыть
			command&=~(1<<0);
			HAL_Delay(DELAY_SEND);
			status^=(1<<0);
			GPIOA->ODR&=~(1<<2);															//выключить магнит
			GPIOF->ODR&=~(1<<1);															//выключить зарядку
			del_val=FLASH_SPEED_OFF;
		}
	}
}
/* USER CODE END PFP */

/**
  * @brief  The application entry point.
  * @retval int
  */
int main(void)
{
  /* MCU Configuration--------------------------------------------------------*/

  /* Reset of all peripherals, Initializes the Flash interface and the Systick. */
  HAL_Init();

  /* Configure the system clock */
  SystemClock_Config();

  /* Initialize all configured peripherals */
  MX_GPIO_Init();
  MX_USART1_UART_Init();
  /* USER CODE BEGIN 2 */
	HAL_Delay(300);
	//после пересборки проекта в кубе, требуется в инициализацию юарта вставить переменную uart_baud, вместо скорости
	if(!(GPIOA->IDR&(1<<3))) {																																					//если перемычка запаянна, то скорость 9600 иначе 115200. 
		//uart_baud=9600;
		//MX_USART1_UART_Init();
	}
	USART1->CR1 = USART_CR1_UE;
	NVIC_EnableIRQ(USART1_IRQn); USART1->CR1 |= USART_CR1_TE | USART_CR1_RE | USART_CR1_RXNEIE;        //разрешение прерывания по приему данных UART1
  
	GPIOA->ODR&=~(1<<2);
	GPIOF->ODR&=~(1<<1);
	/* USER CODE END 2 */

  /* Infinite loop */
  /* USER CODE BEGIN WHILE */
  uint16_t del_toggle=0;
	uint8_t flag_zu=0;
	uint16_t delay_repeat_zu=0;														//для предотвращения повторной зарядки
	
	while (1)
  {
		command_shell();																		//обработка команд
		
		del_toggle++;																				//сквозная задержка для мигания отладочным светодиодом
		if(del_toggle>del_val){															//задержка на 600мс
			del_toggle=0;
			GPIOA->ODR^=(1<<1);																//мигаем
			HAL_Delay(10);																		//мигаем
			GPIOA->ODR^=(1<<1);																//мигаем
		}
		HAL_Delay(1);
		
		//сквозная задержка на повторное включение
		if(delay_repeat_zu) {
			if(!(GPIOA->IDR&(1<<0))) delay_repeat_zu=0;				//если пришло питание когда считает данный счетчик, то сбрасываем его и начинаем счет заного
			delay_repeat_zu++;																//сквозной счетчик для предотвращения повторного включения
		}
		if(delay_repeat_zu>=30000) delay_repeat_zu=0;				//если счетчик досчитал до 10с, то выключаем счетчик
		//сквозная задержка на повторное включение
		
		if(!(GPIOA->IDR&(1<<0))&&del_val>=FLASH_SPEED_OFF&&!flag_zu&&!delay_repeat_zu){ //если пришло питание от зарядки
			HAL_Delay(1000);
			if(!(GPIOA->IDR&(1<<0))){
				GPIOA->ODR|=(1<<2);															//включить магнит
				GPIOF->ODR|=(1<<1);															//включить зарядку
				del_val=FLASH_SPEED_ON;
				flag_zu=1;
			}
		}else if((GPIOA->IDR&(1<<0))&&flag_zu){							//предотвращение повторной зарядки, если команда пришла, а самокат не сняли
			HAL_Delay(1000);
			if(GPIOA->IDR&(1<<0)){
				flag_zu=0;
				delay_repeat_zu++;
			}
		}
		
		//if(GPIOA->IDR&(1<<0)) GPIOA->ODR|=(1<<1); else GPIOA->ODR&=~(1<<1);
    /* USER CODE END WHILE */

    /* USER CODE BEGIN 3 */
  }
  /* USER CODE END 3 */
}

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


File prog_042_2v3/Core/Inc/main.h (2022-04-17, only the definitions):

#define PACKET_START					0x5A																																				//старт посылки
#define PACKET_END						0xFF																																				//конец посылки
#define PACKET_SIZE						11																																					//размер пакета, байт
#define DELAY_SEND						300																																					//задержка после получения команды от сервера на ответное сообщение
#define MSG_ON_1							{0x5A, 0xA5, 0x02, 0x3D, 0x20, 0x02, 0x71, 0x01, 0x00, 0x2C, 0xFF}								//команда 1 для подачи зарядки и включение магнита
#define MSG_ON_2							{0x5A, 0xA5, 0x02, 0x3D, 0x20, 0x02, 0x71, 0x01, 0x00, 0x2C, 0xFF}								//команда 2 для подачи зарядки и включение магнита
#define FLASH_SPEED_ON				300																																					//скорость мигания светодиода, если зарядка включена
#define FLASH_SPEED_OFF				600																																					//скорость мигания светодиода, если зарядка выключена
#define CLEAR_BUF							for(uint8_t i=0;i<PACKET_SIZE;i++) buf_rx[i]=0															//очищаем буфер приема
#define OPEN									GPIOA->ODR|=(1<<2)
#define CLOSE									GPIOA->ODR&=~(1<<2)
#define load1_on_Pin GPIO_PIN_1
#define load1_on_GPIO_Port GPIOF
#define is_charger_Pin GPIO_PIN_0
#define is_charger_GPIO_Port GPIOA
#define debug_led_Pin GPIO_PIN_1
#define debug_led_GPIO_Port GPIOA
#define magnit_on_Pin GPIO_PIN_2
#define magnit_on_GPIO_Port GPIOA
#define baudrate_Pin GPIO_PIN_3
#define baudrate_GPIO_Port GPIOA

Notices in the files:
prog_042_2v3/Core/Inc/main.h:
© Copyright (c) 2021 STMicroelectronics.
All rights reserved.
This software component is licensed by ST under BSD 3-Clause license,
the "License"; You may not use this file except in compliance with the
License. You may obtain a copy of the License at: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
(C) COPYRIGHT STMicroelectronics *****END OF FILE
